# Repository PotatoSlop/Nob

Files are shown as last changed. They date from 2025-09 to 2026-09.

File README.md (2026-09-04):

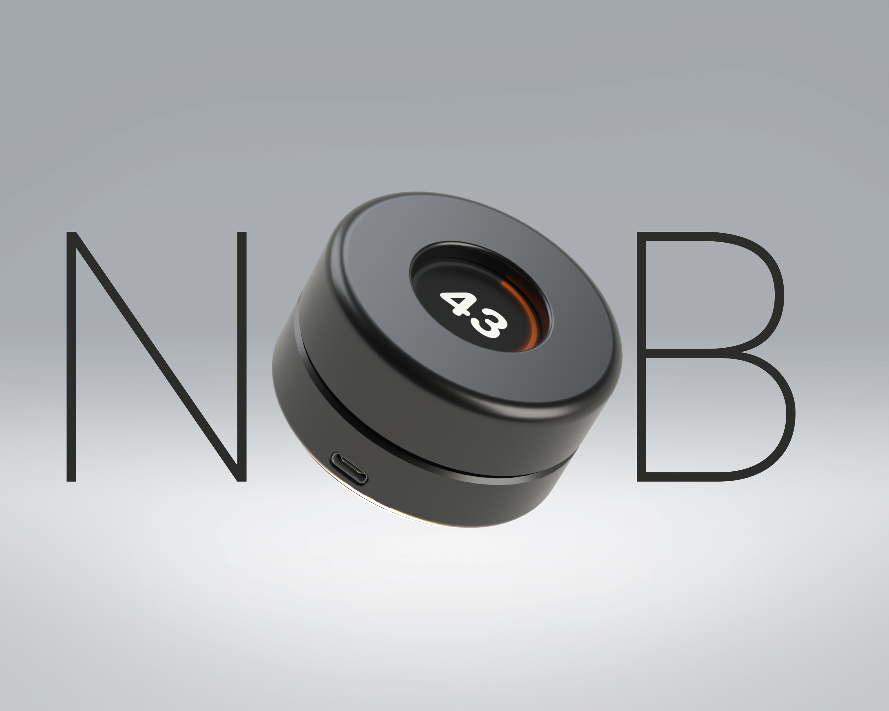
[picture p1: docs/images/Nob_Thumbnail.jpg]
Nob Banner

### NOB is a WIP project to address a personal need for a reasonably priced and customizable rotary encoder for audio control. 
---
### Goals ☑️:
  After switching to a brand-new mechanical keyboard, I lost my built-in volume knob and missed the convenience of having a physical dial to control the volume of my music or videos. I wanted to build a wireless device that looks production-ready and has full functionality while maintaining a minimalistic approach and footprint on my small dorm room desk. 

  With some research on existing solutions, I came across the [Smart Knob Project](https://github.com/scottbez1/smartknob) by Scott Bezek (scottbezek1) whose design utilized a flexible software-defined system for encoding and a brilliant implementation of magnetic encoders in tandem with an elegantly designed display. However, the process of designing around a custom PCB and hot-plate soldering made this project less feasible for practical use. Additionally, the high cost to invest in the tools and parts necessary for that project would not be worth it just for a small learning project. As such, I sought out a more traditional encoder-based solution.

Intended Features 💡:
- Round LCD Display for resource and volume monitoring
- Rotary encoder for granular volume/macro control
- Push button functionality for muting and additional functions
- 400 mAh battery life with USB-C charging interface
- Minimalistic puck design and wireless connectivity via Wi-Fi/BT

---
### Prototyping 📝:
  During the prototyping process, the Sparkfun Electronics Kit was used to breadboard components to a RedBoard. At this stage, I do not have access to an ESP32 microcontroller and thus cannot integrate wireless functionality nor can I directly interface with Bluetooth audio controls. As such, I designed this prototype using a python script, taking advantage of the Pycaw library for audio interfacing with Windows. Being unfamiliar with this Pycaw library, I took advantage of Generative AI and various sources of documentation to aid in drafting a basic volume control system that maps the potentiometer's rotation to a 1-100 scale volume value.

  The limitations of the included 330Ω and 10kΩ resistors proved to be inconvenient given the relatively poor quality of the included 16x2 LCD display with the SparkFun kit: The contrast control (Pin3) required a very specific resistance to "optimize" visibility of the backlight and rendered pixels. 

  Typically, this is done through a potentiometer to fine tune the contrast levels through an analog input (as suggested by the included documentation). However, to avoid sourcing any additional parts for this basic drafting phase, I only had access to a single potentiometer which was being occupied as the actual rotary encoder for the volume dial. As a work around, a constant resistance was provided to the pin using a series of 330 Ω and 10 kΩ resistors to create an equivalent resistance of ~610 Ω, which produced a reasonably usable result.

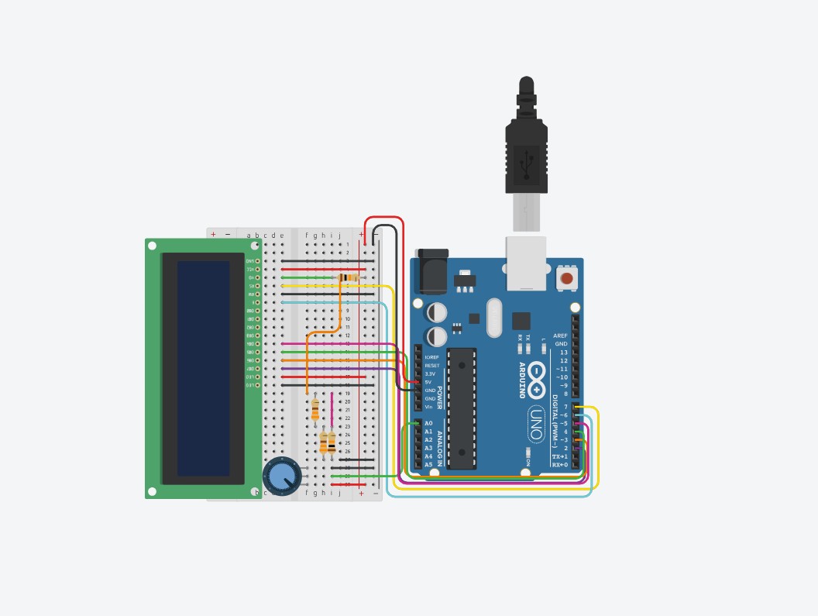
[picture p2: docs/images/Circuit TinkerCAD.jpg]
Overview of the breadboard prototype


The schematic for the prototype circuit can also be accessed here: Schematic of Prototype Circuit

    The resistors in this prototype can be replaced with an equivalent resistor of approximately 600-620Ω (This may vary depending on the selected LCD display chosen for this project).

---

### Mechanical Design and Part Selection ⚙️:

  The undertaking of designing around space and dimensional constraints was a major challenge. From the start, I understood the difficulty in designing around the concentric LCD display module, given the need to run cables from the display to the board without any entanglement that would result from the rotation of the knob. 

  After multiple iterations of designs and sketches of mechanisms, the standard KY-40 rotary encoder was determined to be suboptimal for the given configuration. If an LCD was mounted above the knob on top of the dial surface, the cables would have to run through the interior of the device and eventually wrap around/tangle on the encoder shaft. The only option for the use of this encoder would be to run the cables for the display externally. This, however, was a design sacrifice that violated the vision and principles of the project and thus eliminated the use of this encoder type entirely. 

  [Sketches of designs 📗](https://github.com/PotatoSlop/Nob/blob/main/docs/images/Ideas.pdf)

  With some research, it was settled that a hollow-shaft ring encoder (the Alps Alpine EC50A0920404) would suffice for this project. The decision to utilize a ring encoder came from a similar project dubbed the [Focus Dial](https://github.com/sb-ocr/focus-dial) by Salim Benbouziyane (sb-ocr) and Uwe Arzt (uwearzt). 

  Despite the central cavity being optimal for LCD wiring, the opening also means that a built-in push button is not available and must be implemented separately. To power this device, a Seeed Studio XIAO ESP32-S3 is used for its support of Bluetooth 5.0, small footprint, sufficient pinouts, and support for battery charging via the USB-C port. To meet the wireless requirement, power is supplied via a standard 500 mAh LiPo battery whose 2-pin JST connection is stripped and the wires fully soldered to the ESP board. To minimize cost and simplify the design, a standard 12×12 mm momentary push button (SparkFun) is used for the central push button system. Below is an early mockup cross section of the project:

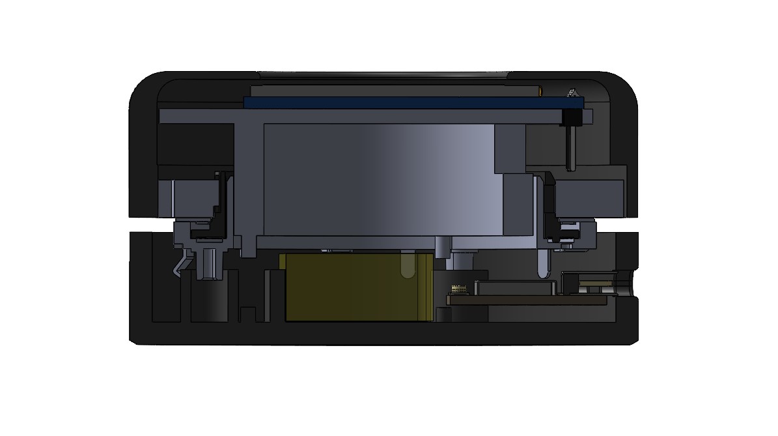
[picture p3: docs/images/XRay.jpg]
WIP Current Design 9-17-25

---
  The parts can all be found online on various shopping platforms following:
  - Rotary Encoder (hollow shaft): [Alps Alpine EC50A0920404 — DigiKey](https://www.digikey.com/en/products/detail/alps-alpine/EC50A0920404/21721676)
  - Microcontroller: [Seeed Studio XIAO ESP32-S3](https://www.seeedstudio.com/XIAO-ESP32S3-p-5627.html)
  - Push-button (12×12 mm momentary): [SparkFun](https://www.sparkfun.com/momentary-pushbutton-switch-12mm-square.html)
  - TFT LCD Display (1.28 in, GC9A01, SPI round): [AliExpress](https://www.aliexpress.us/item/3256808438527640.html)
  - Battery (3.7 V 500 mAh LiPo, 702030): [AliExpress](https://www.aliexpress.us/item/3256809769151614.html)
  - Rubber Feet (6×2 mm silicone, 100 pc): [AliExpress](https://www.aliexpress.us/item/3256806196171413.html)

The bill of materials for this project comes out to just under **$24 USD** without the 3D printed components. _(This may vary depending on where parts are sourced and the shipping costs to your area)_

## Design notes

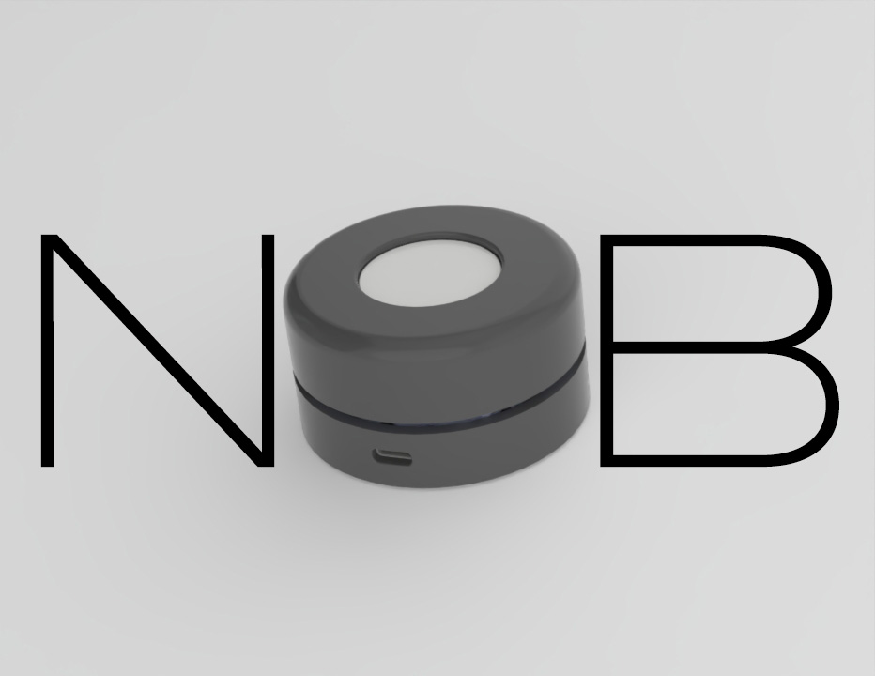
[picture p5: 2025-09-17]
docs/images/Nob_Thumbnail_Text.jpg

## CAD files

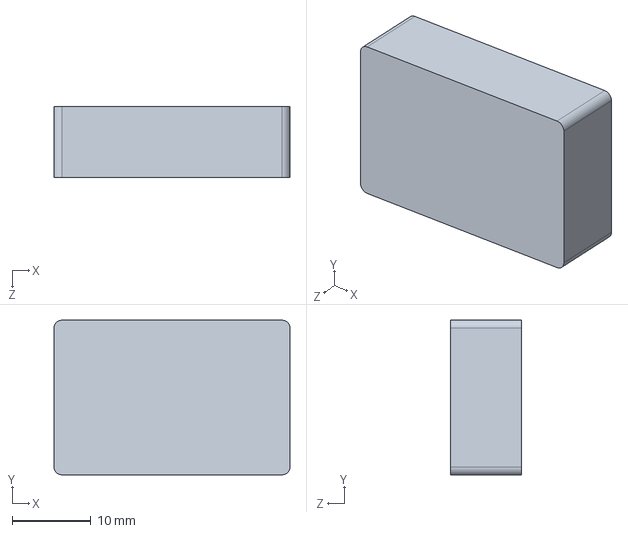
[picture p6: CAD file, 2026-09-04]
SLDPRT/Reference 3D Models/BatteryReference.SLDPRT
30.0 x 19.7 x 9.00 mm

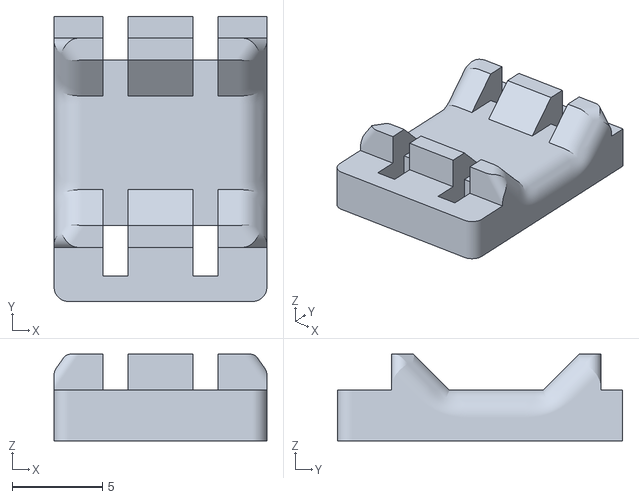
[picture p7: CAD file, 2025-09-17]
SLDPRT/Reference 3D Models/focus-dial-main/focus-dial-main/cad/STLs/Button Holder.stl
11.8 x 15.8 x 4.81

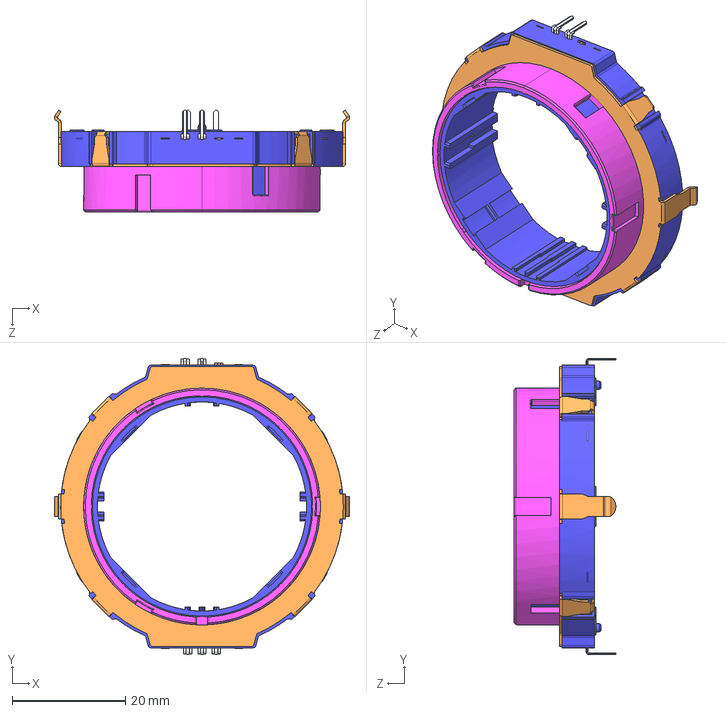
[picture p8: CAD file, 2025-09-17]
SLDPRT/Reference 3D Models/product_3dcad_ec50a0920404_en_6490e64209/EC50A0920404/EC50A0920404.STEP
52.2 x 52.4 x 18.0 mm

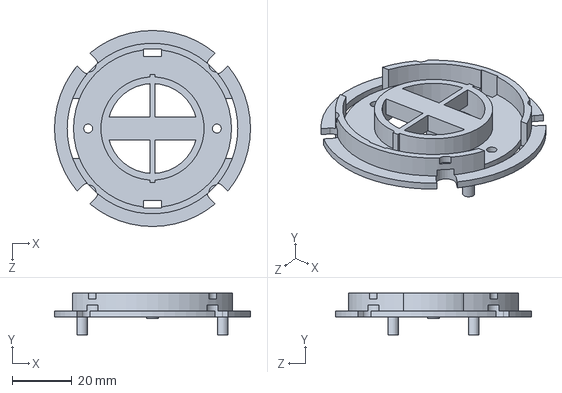
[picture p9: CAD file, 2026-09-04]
SLDPRT/v3PLA_base_encoder_spring_var.SLDPRT
65.5 x 14.0 x 65.5 mm

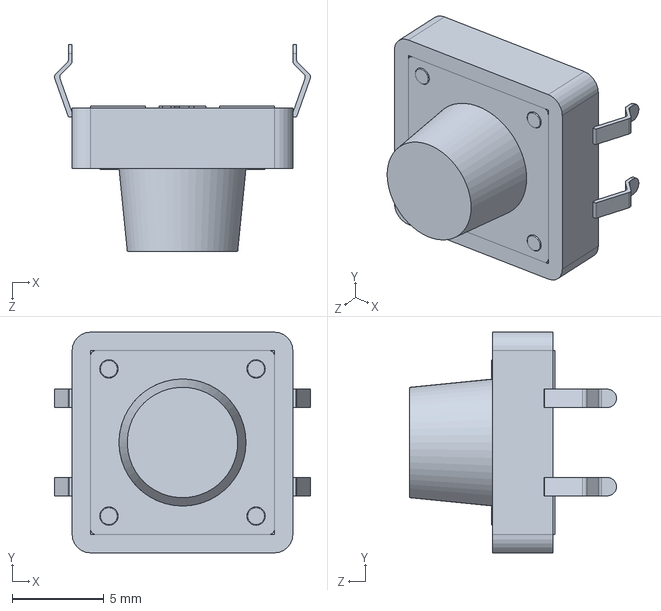
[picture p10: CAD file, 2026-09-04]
SLDPRT/Reference 3D Models/12mm x 12mm Tactile switch Button.SLDPRT
13.9 x 12.0 x 11.2 mm

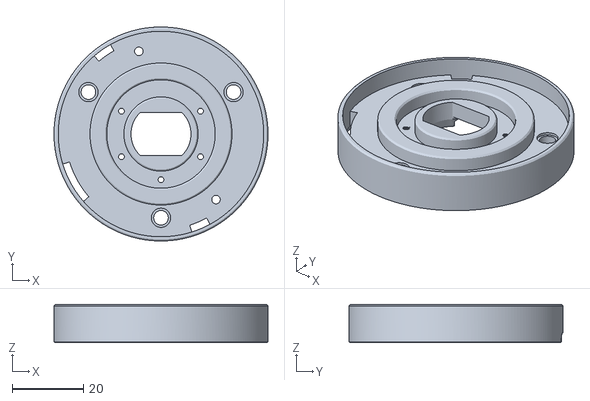
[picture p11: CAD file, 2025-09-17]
SLDPRT/Reference 3D Models/focus-dial-main/focus-dial-main/cad/STLs/Encoder Bottom.stl
60.0 x 60.0 x 10.7

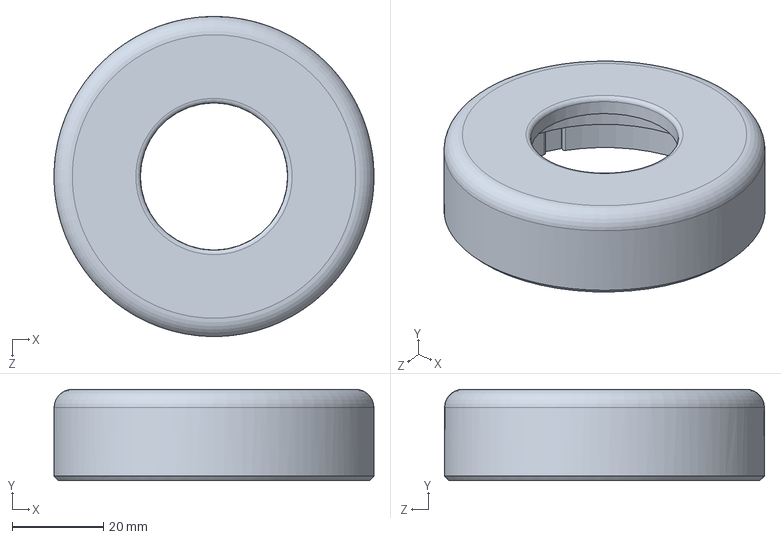
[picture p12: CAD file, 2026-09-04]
SLDPRT/Shell_top2_1.SLDPRT
70.0 x 20.0 x 70.0 mm

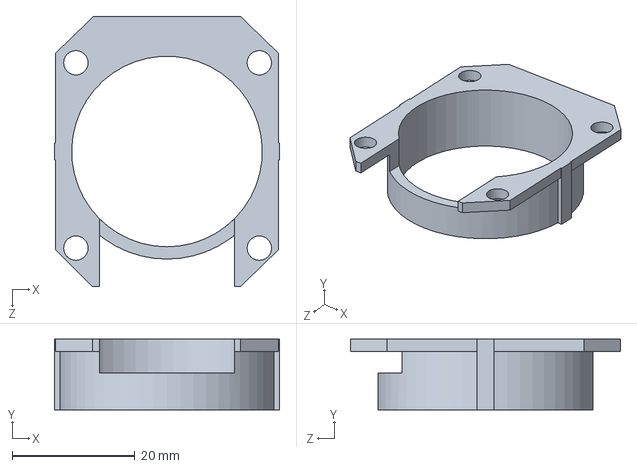
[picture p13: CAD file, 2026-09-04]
SLDPRT/inner_tube.SLDPRT
36.6 x 11.5 x 44.0 mm

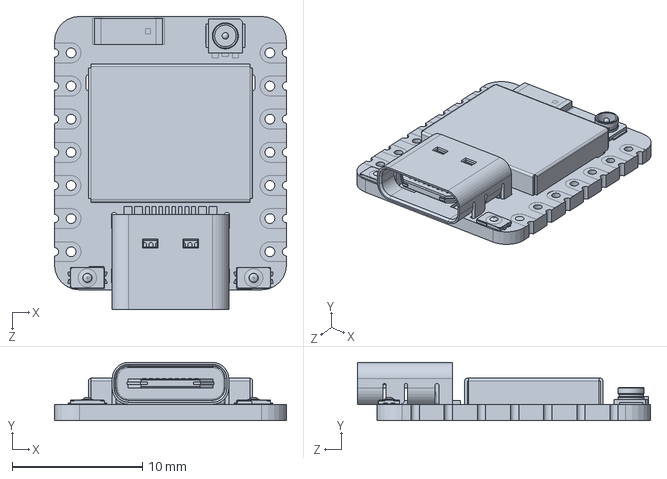
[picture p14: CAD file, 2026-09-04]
SLDPRT/Reference 3D Models/esp32.SLDPRT
17.8 x 4.46 x 22.5 mm

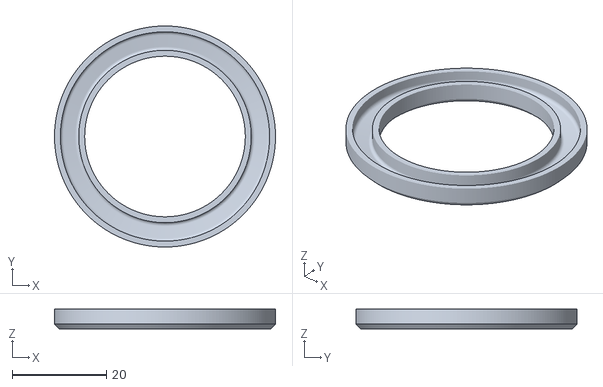
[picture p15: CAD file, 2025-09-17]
SLDPRT/Reference 3D Models/focus-dial-main/focus-dial-main/cad/STLs/Diffuser Mold.stl
46.8 x 46.8 x 4.20

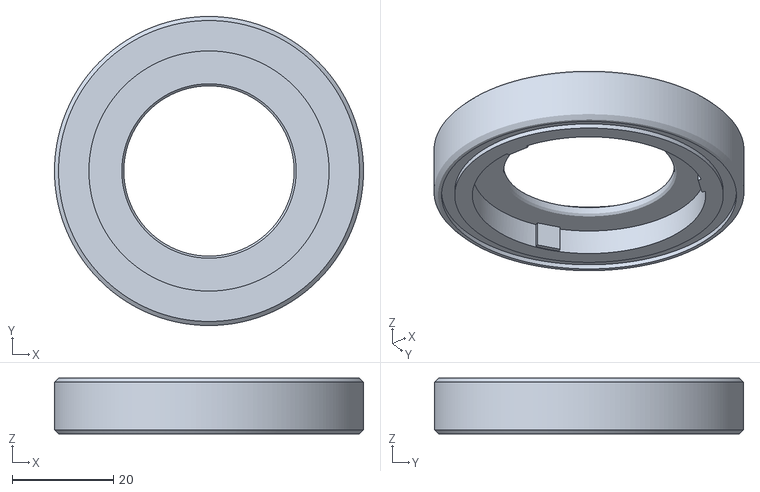
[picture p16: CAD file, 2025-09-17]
SLDPRT/Reference 3D Models/focus-dial-main/focus-dial-main/cad/STLs/Central Ring.stl
61.0 x 61.0 x 11.0

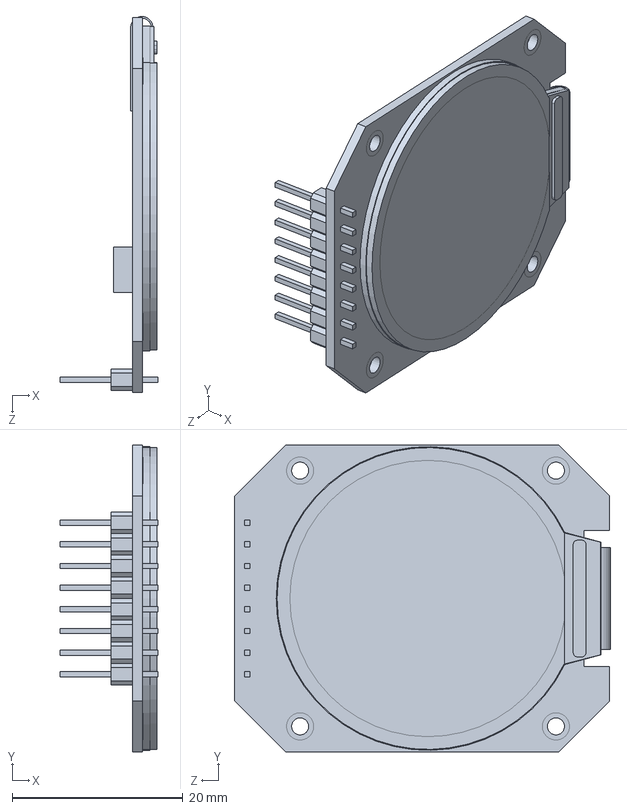
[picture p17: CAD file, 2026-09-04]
SLDPRT/Reference 3D Models/LCD 1.28 Inch GC9A01.SLDPRT
11.5 x 36.0 x 44.1 mm

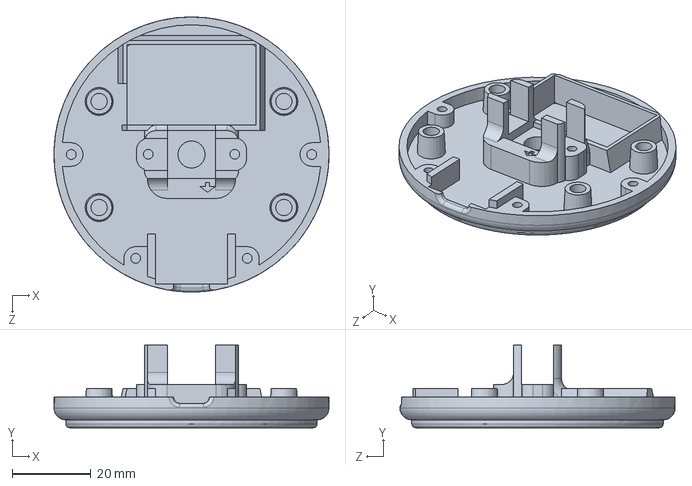
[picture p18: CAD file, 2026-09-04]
SLDPRT/v3baseShellBotHalf.SLDPRT
70.0 x 21.0 x 70.0 mm

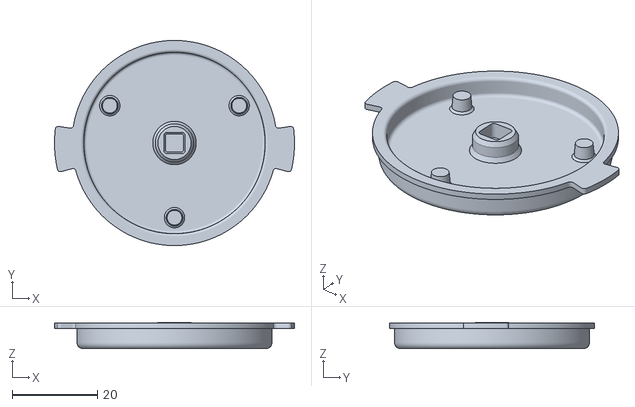
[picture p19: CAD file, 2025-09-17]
SLDPRT/Reference 3D Models/focus-dial-main/focus-dial-main/cad/STLs/Bottom Button.stl
56.4 x 48.2 x 6.20

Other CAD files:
SLDPRT/Full.SLDASM
SLDPRT/v3baseCollar.SLDPRT
SLDPRT/Reference 3D Models/focus-dial-main/focus-dial-main/cad/STLs/Bezel.stl
SLDPRT/shell_top_inner_2.SLDPRT
SLDPRT/Reference 3D Models/focus-dial-main/focus-dial-main/cad/STLs/Bottom.stl
SLDPRT/Reference 3D Models/focus-dial-main/focus-dial-main/cad/STLs/Button Cap.stl
SLDPRT/Reference 3D Models/focus-dial-main/focus-dial-main/cad/STLs/Central Shaft.stl
SLDPRT/Reference 3D Models/focus-dial-main/focus-dial-main/cad/STLs/Face.stl
SLDPRT/Reference 3D Models/focus-dial-main/focus-dial-main/cad/STLs/Screen Backing.stl
SLDPRT/v3baseShellTopHalf.SLDPRT

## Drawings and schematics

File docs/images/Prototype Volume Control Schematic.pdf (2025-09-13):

A

1 | 2 | 3 | 4 | 5 | 6

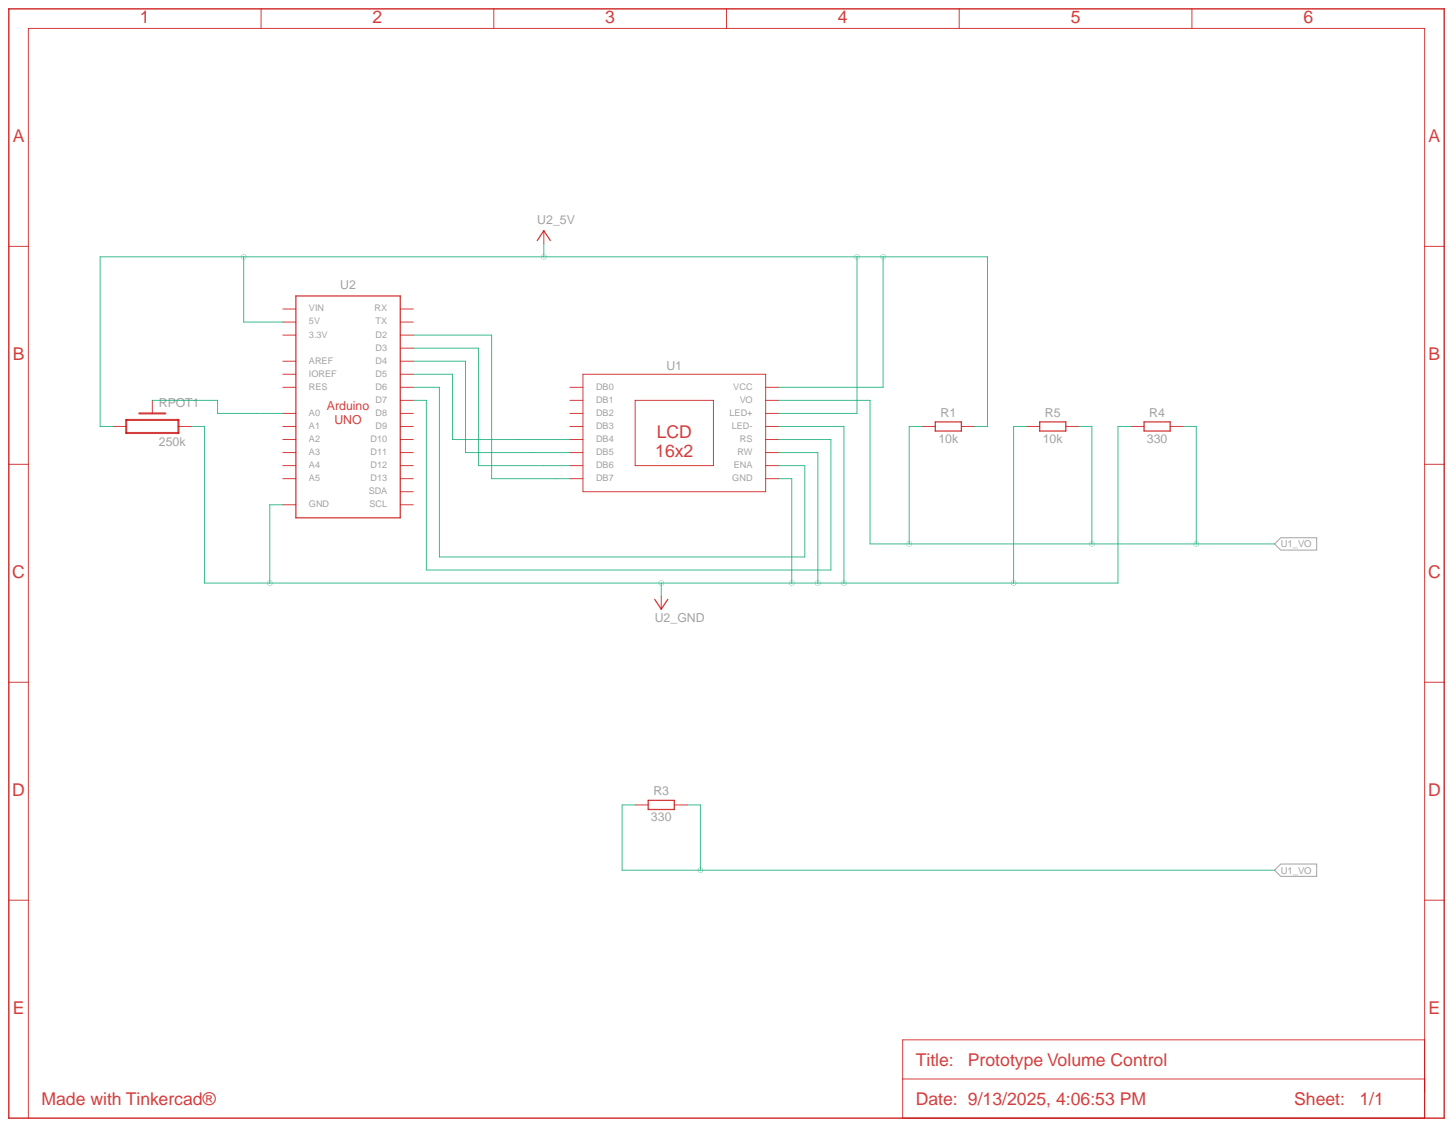
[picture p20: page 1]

Title: Prototype Volume Control

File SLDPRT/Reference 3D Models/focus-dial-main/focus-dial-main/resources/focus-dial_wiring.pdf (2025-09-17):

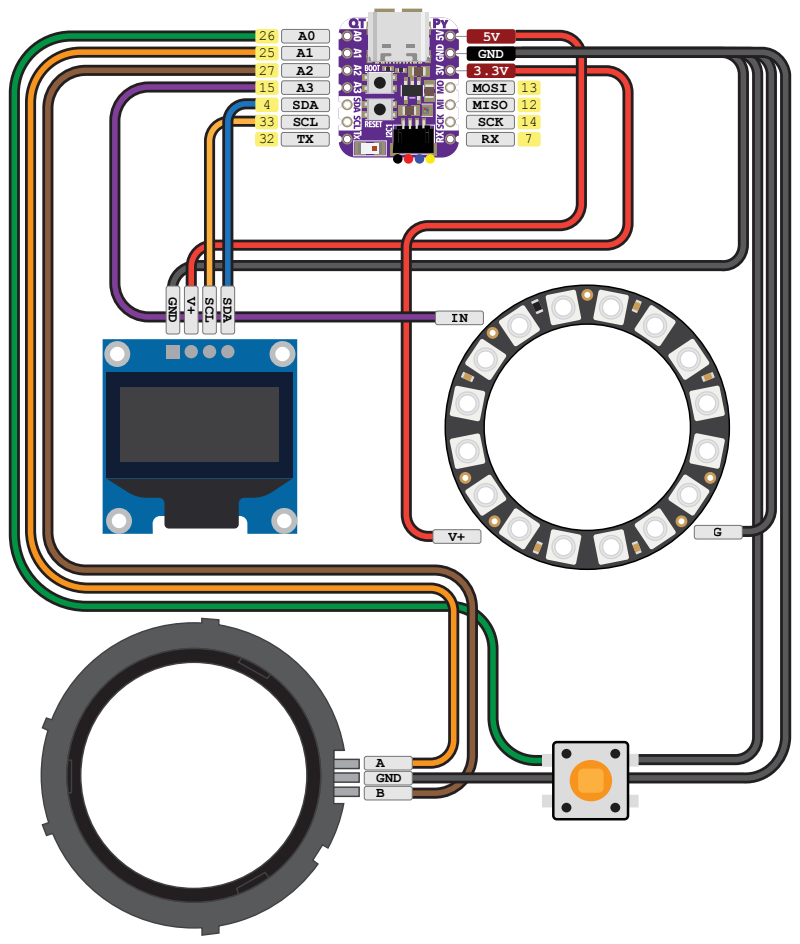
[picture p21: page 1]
33 SCL; 25 A1 27 A2 15 A3 4 SDA; GND 3.3V MOSI 13 MISO 12 SCK 14; GND; V+ SCL; SDA; A GND B

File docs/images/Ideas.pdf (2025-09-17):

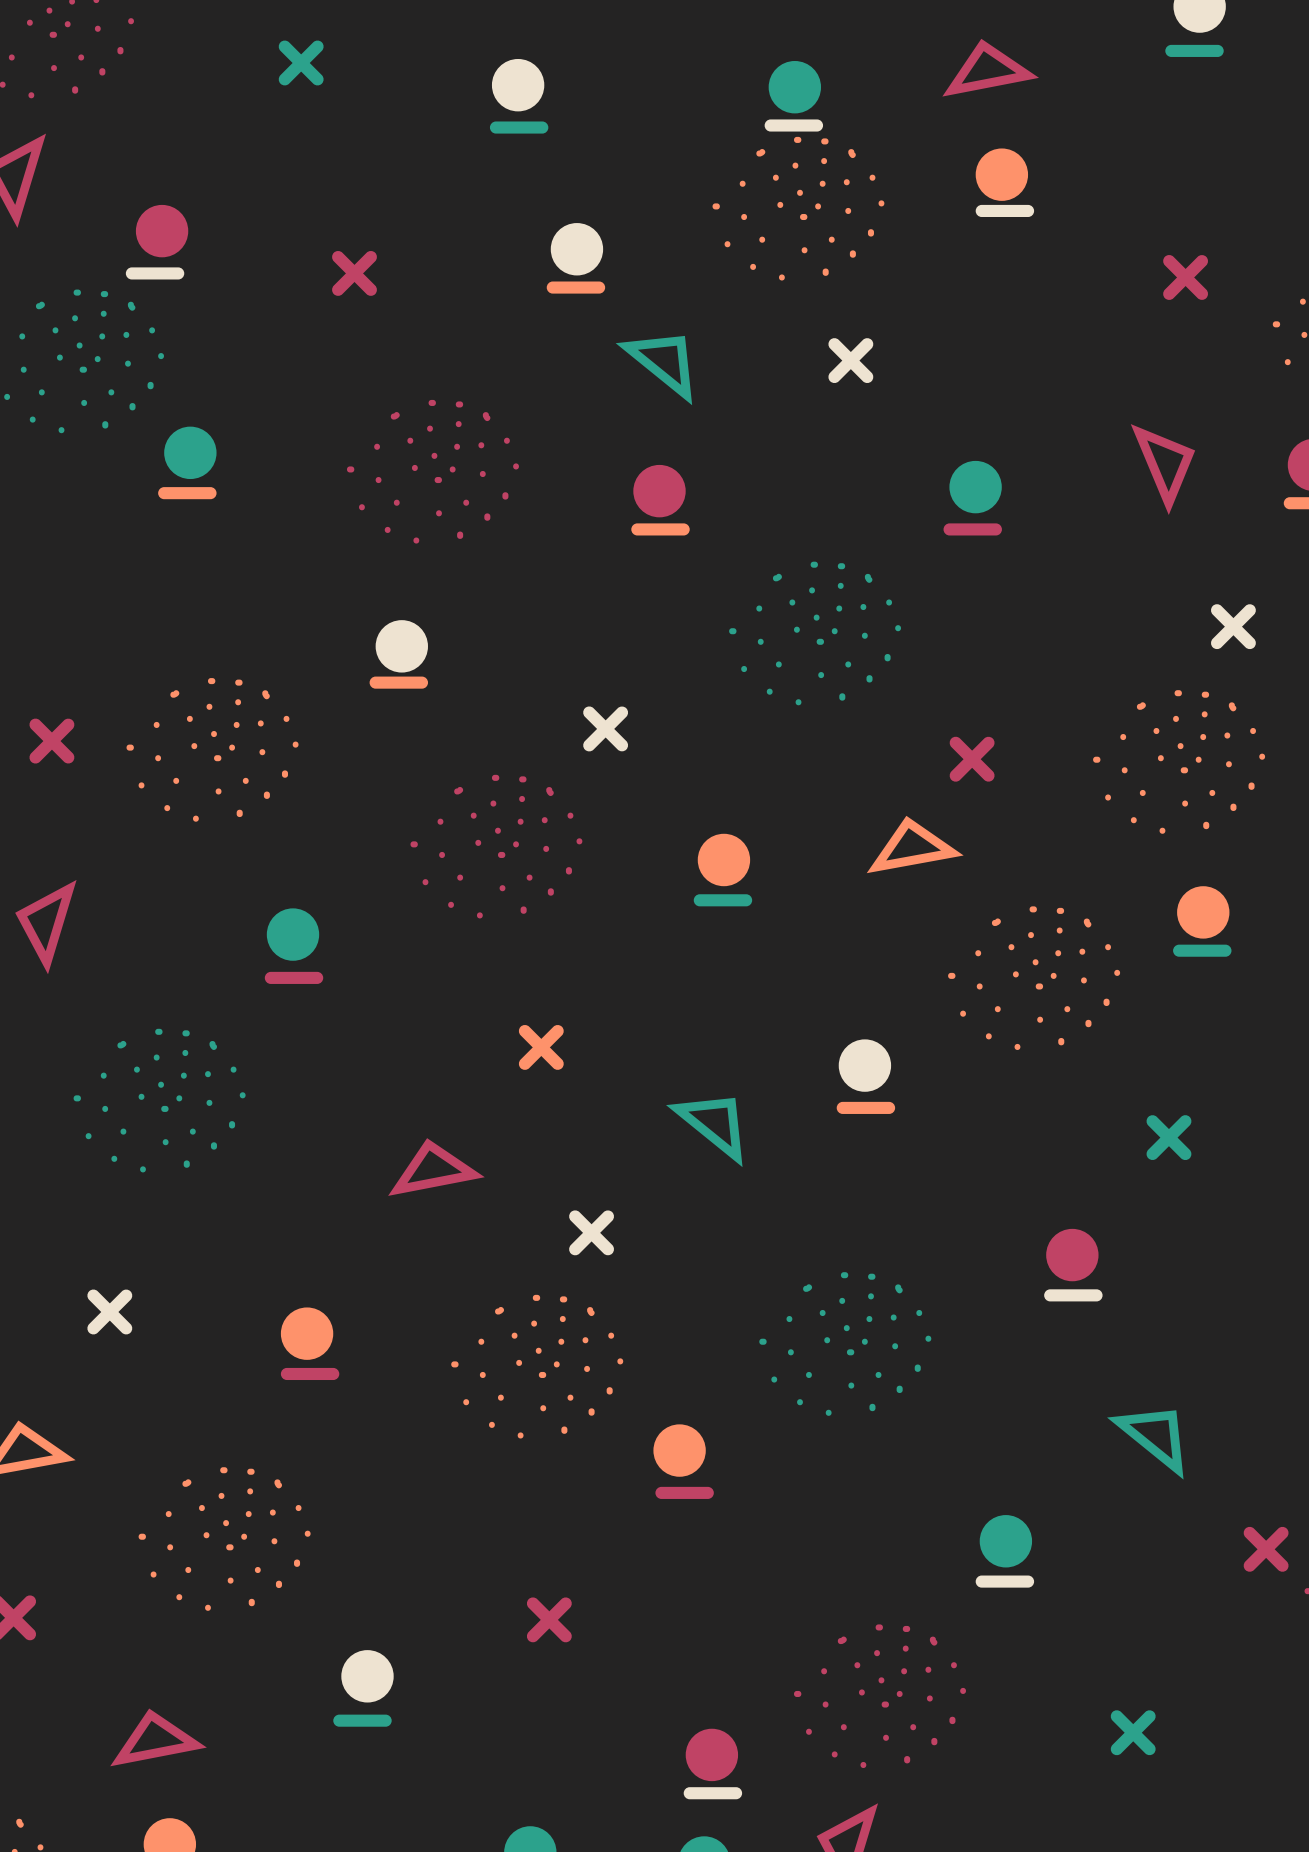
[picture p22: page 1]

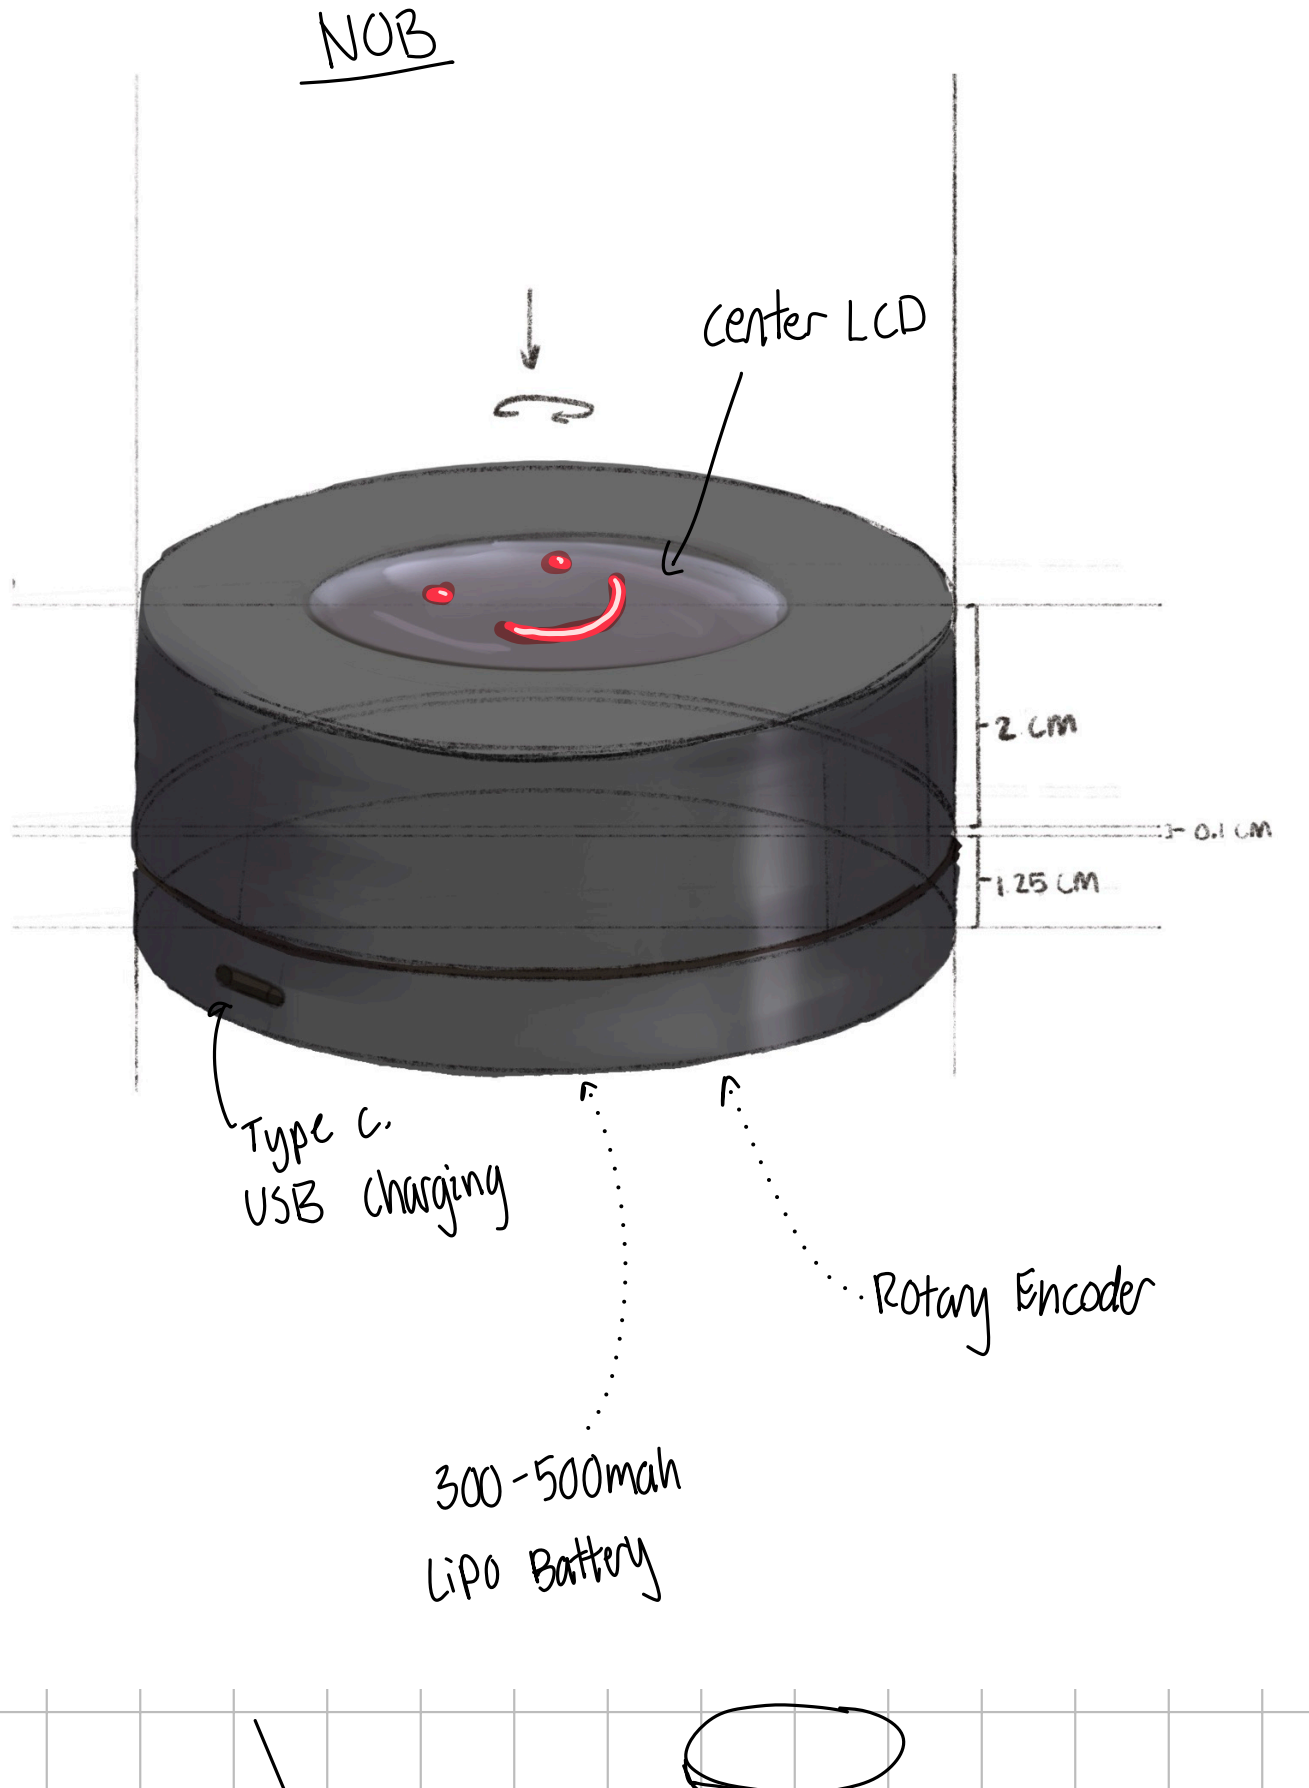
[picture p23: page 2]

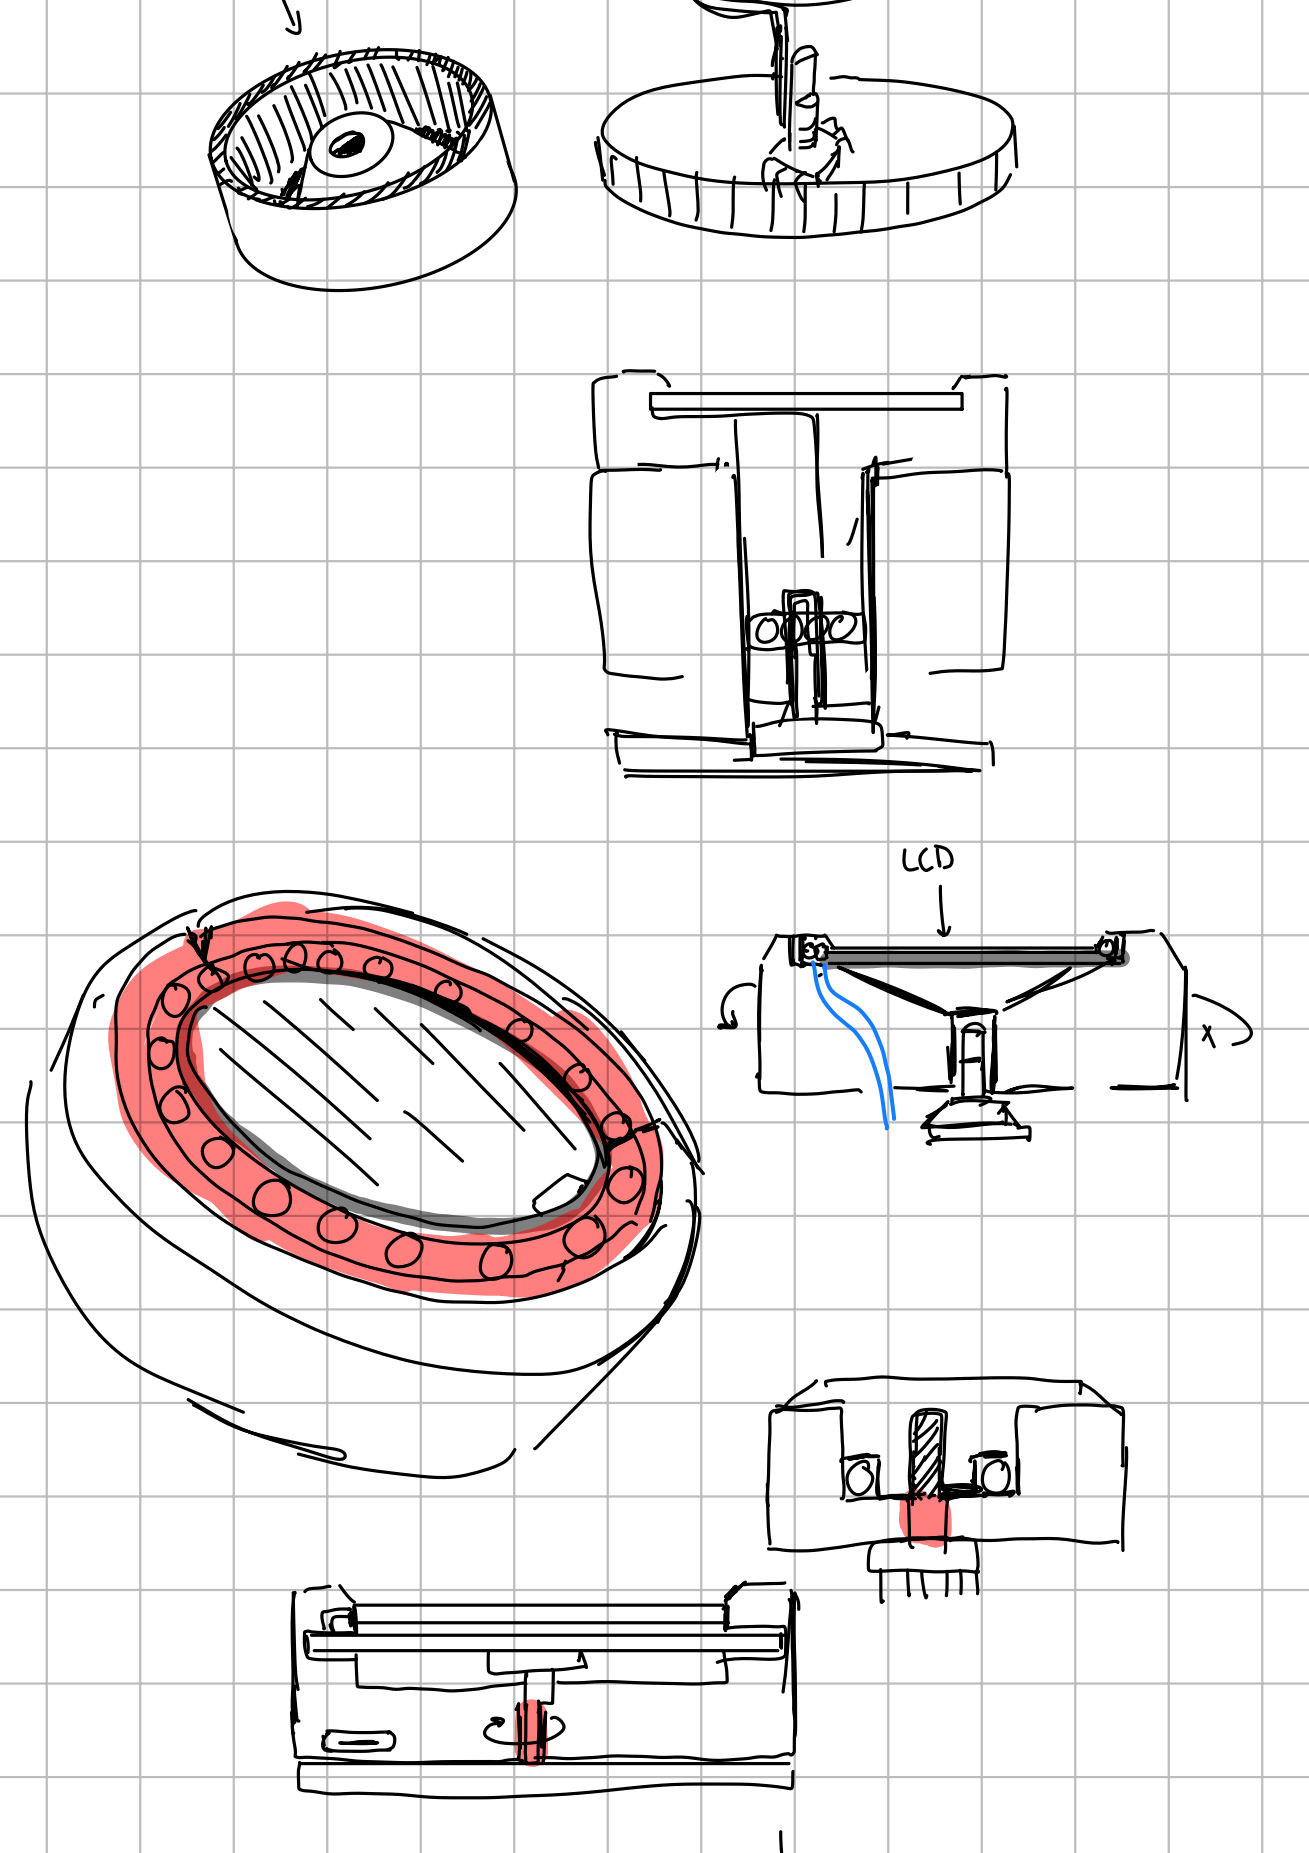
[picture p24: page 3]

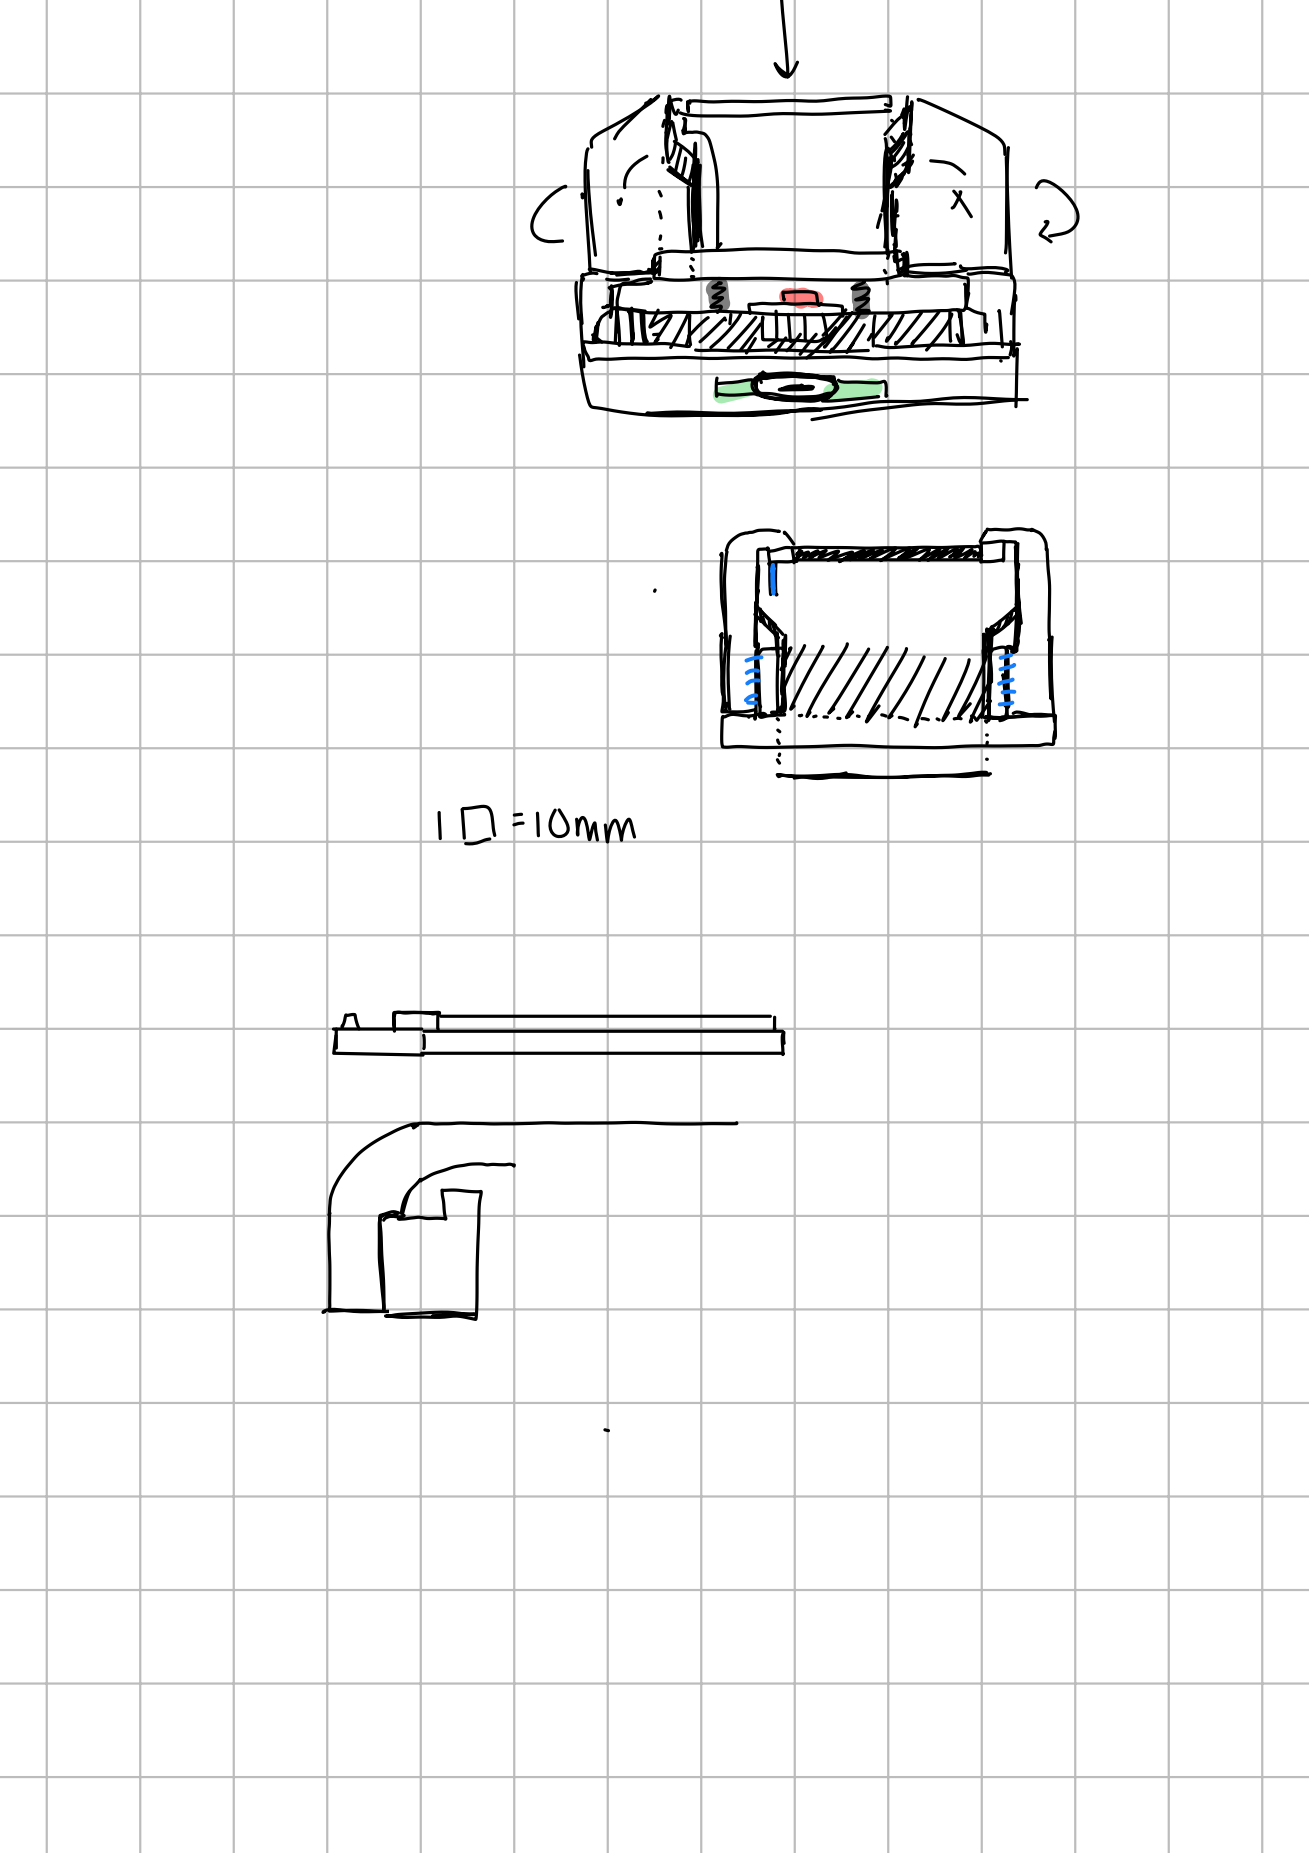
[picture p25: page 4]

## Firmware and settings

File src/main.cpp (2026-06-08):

#include <Arduino.h>
#include <SPI.h>
#include <Arduino_GFX_Library.h>
#include <OneButton.h>

// ----------------------------- Encoder + button -----------------------------
#define DIAL_A_PIN 1
#define DIAL_B_PIN 0
#define BTN_PIN    3

OneButton btn = OneButton(BTN_PIN, true);

// Ben Buxton's bounce-immune quadrature state table (full step).
// It only emits a step when a COMPLETE valid A/B sequence is walked; contact
// bounce produces invalid transitions that rattle between states and emit
// nothing -- so no phantom jumps, reversals, or dropped detents.
// 4x quadrature decoder: counts every valid A/B transition (= one per detent on
// this Gray-per-click encoder). The lookup gives +1/-1 for legal steps and 0 for
// illegal jumps; a bounce that flips back then forward nets to zero -> self-correcting.
// Index = (prevAB << 2) | curAB.
static const int8_t qtable[16] = {
   0, -1,  1,  0,
   1,  0,  0, -1,
  -1,  0,  0,  1,
   0,  1, -1,  0
};

const int ROTARY_MIN = 0;
const int ROTARY_MAX = 100;
const int DETENT_DIV = 2;   // raw transitions per detent (tune: 1, 2, or 4)
int     rotaryPos = 0;
int     rawAccum  = 0;
uint8_t prevAB    = 0;

// Polled (NOT an interrupt) — call often from loop(). Decodes every transition
// (bounce-tolerant), then emits one detent step per DETENT_DIV transitions.
void pollEncoder() {
  uint8_t curAB = (digitalRead(DIAL_A_PIN) << 1) | digitalRead(DIAL_B_PIN);
  if (curAB != prevAB) {
    rawAccum += qtable[(prevAB << 2) | curAB];
    prevAB = curAB;
    while (rawAccum >= DETENT_DIV)  { rawAccum -= DETENT_DIV; if (rotaryPos < ROTARY_MAX) rotaryPos++; }
    while (rawAccum <= -DETENT_DIV) { rawAccum += DETENT_DIV; if (rotaryPos > ROTARY_MIN) rotaryPos--; }
  }
}

// --------------------------- Display: GC9A01 240x240 ------------------------
// Wiring (display pin -> ESP32-C3 SuperMini GPIO):
//   SDA->GPIO6  SCL->GPIO7  DC->GPIO5  CS->GPIO4  RES->GPIO10
//   VCC->3V3    GND->GND    BLK->3V3
#define GFX_SCK  7
#define GFX_MOSI 6
#define GFX_MISO -1   // write-only panel
#define GFX_DC   5
#define GFX_CS   4
#define GFX_RST  10

const int SCREEN_W = 240;
const int SCREEN_H = 240;

#define COL_BLACK 0x0000
#define COL_WHITE 0xFFFF
#define COL_GREY  0x7BEF

Arduino_DataBus *bus = new Arduino_HWSPI(GFX_DC, GFX_CS, GFX_SCK, GFX_MOSI, GFX_MISO);
Arduino_GFX    *gfx = new Arduino_GC9A01(bus, GFX_RST, 0 /* rotation */, true /* IPS */);

void handleButtonClick();
void drawVolume(int v);

int lastShown = -1;

void setup() {
  Serial.begin(115200);
  delay(300);
  Serial.println();
  Serial.println("=== Nob booted ===");

  // Encoder: internal pull-ups (common pin -> GND). Polled in loop(), no ISR.
  pinMode(DIAL_A_PIN, INPUT_PULLUP);
  pinMode(DIAL_B_PIN, INPUT_PULLUP);

  btn.attachClick(handleButtonClick);

  // Display
  gfx->begin();
  gfx->fillScreen(COL_BLACK);
  gfx->setTextColor(COL_GREY);
  gfx->setTextSize(2);
  int16_t x1, y1;
  uint16_t w, h;
  gfx->getTextBounds("VOLUME", 0, 0, &x1, &y1, &w, &h);
  gfx->setCursor((SCREEN_W - w) / 2, 50);
  gfx->print("VOLUME");

  lastShown = rotaryPos;
  drawVolume(lastShown);
}

void loop() {
  pollEncoder();
  int v = rotaryPos;

  if (v != lastShown) {
    lastShown = v;
    Serial.print("Val: ");
    Serial.println(v);
    drawVolume(v);
  }

  // Heartbeat so the monitor always shows life (and we can tell running vs crashed).
  static uint32_t last = 0;
  if (millis() - last >= 1000) {
    last = millis();
    Serial.print("alive, vol=");
    Serial.println(v);
  }

  btn.tick();
}

void handleButtonClick() {
  Serial.println("Click");
}

// Big volume number, centred. Clears a band first, then centres via measured bounds.
void drawVolume(int v) {
  char buf[8];
  snprintf(buf, sizeof(buf), "%d", v);

  gfx->setTextSize(6);
  int16_t x1, y1;
  uint16_t w, h;
  gfx->getTextBounds(buf, 0, 0, &x1, &y1, &w, &h);

  gfx->fillRect(0, SCREEN_H / 2 - 30, SCREEN_W, 60, COL_BLACK);
  gfx->setTextColor(COL_WHITE);
  gfx->setCursor((SCREEN_W - w) / 2, SCREEN_H / 2 - h / 2);
  gfx->print(buf);
}

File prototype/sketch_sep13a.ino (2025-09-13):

#include <LiquidCrystal.h>

LiquidCrystal lcd(7, 6, 5, 4, 3, 2);

const int POT_PIN = A0;
const int POT_MIN = 0;
const int POT_MAX = 1023;

int lastSentPercent = -1; // Stores latest % sent to volume control

// Custom characters for display volume bars
byte bar_1[8] = { 0b10000, 0b10000, 0b10000, 0b10000, 0b10000, 0b10000, 0b10000, 0b10000 }; //8 rows of pixels, 5 total bars 
byte bar_2[8] = { 0b11000, 0b11000, 0b11000, 0b11000, 0b11000, 0b11000, 0b11000, 0b11000 };
byte bar_3[8] = { 0b11100, 0b11100, 0b11100, 0b11100, 0b11100, 0b11100, 0b11100, 0b11100 };
byte bar_4[8] = { 0b11110, 0b11110, 0b11110, 0b11110, 0b11110, 0b11110, 0b11110, 0b11110 };
byte bar_5[8] = { 0b11111, 0b11111, 0b11111, 0b11111, 0b11111, 0b11111, 0b11111, 0b11111 };

void setup() {
  Serial.begin(9600);
  lcd.begin(16, 2);
  lcd.createChar(0, bar_1);
  lcd.createChar(1, bar_2);
  lcd.createChar(2, bar_3);
  lcd.createChar(3, bar_4);
  lcd.createChar(4, bar_5);
}

void loop() {
  int currentPotValue = analogRead(POT_PIN);
  
  // Map percentage values of volume to calibrated range of pot.
  int volumePercent = map(currentPotValue, POT_MIN, POT_MAX, 0, 100);
  volumePercent = constrain(volumePercent, 0, 100);

  if (volumePercent != lastSentPercent) {
    Serial.println(volumePercent); //Update vol. percentage --> python script
    lastSentPercent = volumePercent; 
  }

  // LCD Styling
  lcd.setCursor(0, 0);
  lcd.print("Volume: ");
  if (volumePercent < 10) lcd.print("  ");
  if (volumePercent >= 10 && volumePercent < 100) lcd.print(" ");
  lcd.print(volumePercent);
  lcd.print("%");
  drawVolumeBar(volumePercent);
  
  delay(50);
}

void drawVolumeBar(int percent) {
  lcd.setCursor(0, 1);
  int pixels = map(percent, 0, 100, 0, 80);
  int fullBlocks = pixels / 5;
  int partialPixels = pixels % 5;

  for (int i = 0; i < fullBlocks; i++) { 
    lcd.write(byte(4)); 
  }

  if (fullBlocks < 16 && partialPixels > 0) { 
    lcd.write(byte(partialPixels - 1)); 
  }
  int currentBarLength = fullBlocks + (partialPixels > 0 ? 1 : 0);

  for (int i = currentBarLength; i < 16; i++) {
    lcd.print(" "); 
  }
}

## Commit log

2025-09-13 Functioning prototype with breadboard components via Sparkfun kit elements - Python integration for windows media volumeControl - Arduino code with potentiometer for testing - 16x2 LCD display for vo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
2025-09-13 Schematics and Circuit design images
2025-09-17 Add 3d Models [WIP]
    [12mm x 12mm Tactile switch Button.step, 12mm x 12mm Tactile switch.dwg, 12mm x 12mm Tactile switch.iges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]
2026-09-04 File updates
    [12mm x 12mm Tactile switch Button.SLDPRT, 12mm x 12mm Tactile switch Button.step, 12mm x 12mm Tactile switch.dwg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]
2026-09-04 Updated Readme with new banner
    Updated image banner to reflect renderings of prototype. Parts lists is still a WIP. Schematics still need an update (Soon)
2026-09-04 Update parts list to new components and reconcile prose
    Swap BOM to Alps EC50A0920404 encoder, XIAO ESP32-S3, 12x12mm
    SparkFun button, 1.28" GC9A01 TFT, 500mAh 702030 LiPo, and 6x2mm
    silicone feet. Strip AliExpress tracking params and align the
    Mechanical Design narrative with the new parts.
2026-09-04 Revise bill of materials and update costs
    Updated the bill of materials cost and removed a spring item from the list.
